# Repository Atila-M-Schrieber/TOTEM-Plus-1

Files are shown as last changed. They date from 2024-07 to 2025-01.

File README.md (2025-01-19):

<picture align="center">
  <source media="(prefers-color-scheme: dark)" srcset="/docs/images/TOTEM_logo_dark.svg">
  <source media="(prefers-color-scheme: light)" srcset="/docs/images/TOTEM_logo_bright.svg">
  TOTEM logo
</picture>

<h1 align="center">T O T E M</h1>
<h2 align="center">Plus 1</h2>

TOTEM Plus 1 is a modified version of the TOTEM keyboard, with an extra pinky key.
It is a 40 key column-staggered choc split keyboard. It is meant to be used with a SEEED XIAO BLE or RP2040.
The build process is pretty much identical, except you need electronics for two more keys.
(Sockets, diodes, switches, and keycaps)
[Here](https://www.hackster.io/geist/totem-a-tiny-splitkeyboard-with-splay-cb2e43) you can read about the process of making it.

The case can fit into a magnetic travel case, like the one
made by [Compression Keyboards](https://compressionkeyboards.com/products/4c-3d-printed-case-kit).
The current V2 case is still missing accenting and some optimization, but is otherwise ready for use,
and works great with the V0 travel case.

While the layout is pretty much identical to the [KLOR KONRAD](https://github.com/GEIGEIGEIST/KLOR),
I prefer the æsthetics of the TOTEM, and I have no need for a rotary encoder on this keyboard.
Also, I wanted to dip my toes into PCB editing, and this seemed like a slightly bigger challenge
(it was) than removing the rotary encoder from the KLOR.

### Additional features:
- [x] I like the idea of using a switch (like the on/off one) as a way to turn a layer on/off,
      especially for a usecase like gaming. Since I'm going to use this wirelessly, I might add
      another switch (same as the power on/off switch) on top of where where the TRRS
      jack would go. I can probably add the footprint without even removing the TRRS footprints.
      This would mean another row or column from one of the UART pins
        - If I'm using the UART pins for something else, like trackpoint support, this won't work
          (or only on one side of the keyboard, ie 'gaming mode' switch on left side, trackpoint on right)
        - In implementing this **I swapped the poles of the TRRS jack** (GND -> TX -> VCC -> GND), so take note
          if you do end up using the wired version and need to debug the TTRS cable (for some reason).
        - There is a lot of overlap with the TRRS through holes - while it might be harder to solder
          due to the conduction, there is plenty of space to solder the switch leads.
    - Alternatively I can add an I/O expander (MCP23017), which is already supported in ZMK
- [x] Splitting the current top half of the case into top and middle sections, where the middle section
      would be the key grid + the 'skirt' of the thumb cluster. This would eliminate the need for supports,
      and would make the exposed key grid take on the texture of the print bed.
      It also allows the removal of the top & bottom parts without having to remove all the keycaps.
- [ ] The current tenting and anti-slip solutions work, but could be improved,
      for example by integrating magnetic stands, for example using a MagSafe phone stand as the mounting and tenting solution.
- [ ] Trackpoint support: ([see this pull request / fork](https://github.com/zmkfirmware/zmk/pull/1751))
      This would be a replacement for the TRRS jacks, since it uses UART.
      I have ordered [this module](https://www.aliexpress.com/item/1005004696754100.html),
      so I'll see if/how I can use it.
***

(The Plus in the 'totem pole' logo is (supposed to be) a hammerhead)

## LAYOUT

TOTEM layout

***

## PCB

[Here](/PCB/) you can find the KiCad files and Gerbers for the TOTEM.

***

## CASE

You can use the TOTEM without a case, but [here](/case/) you can find one I made for it.

***

## BUILD GUIDE

The build guide for the TOTEM can be found [here](/docs/buildguide.md).

***

## FIRMWARE

[My ZMK config](https://github.com/Atila-M-Schrieber/zmk-config) for the TOTEM Plus 1 (wireless with a dongle, using the XIAO BLE)

[Original dongle ZMK config](https://github.com/eigatech/zmk-config/tree/totem-dongle) for the TOTEM wireless + dongle build

***

## PHOTOS

This is the TOTEM Plus 1 in the V2 case optimized for FDM printing.
The case was printed using Gembird gray PETG on an Ender 3 V3 Plus with a 0.6mm nozzle and 0.3mm layer height.
The keycaps used can be found [here](https://github.com/sporkus/PseudoMakeMeKeyCapProfiles) (the Chicago Stenographer version),
and were printed on a Prusa SL1.

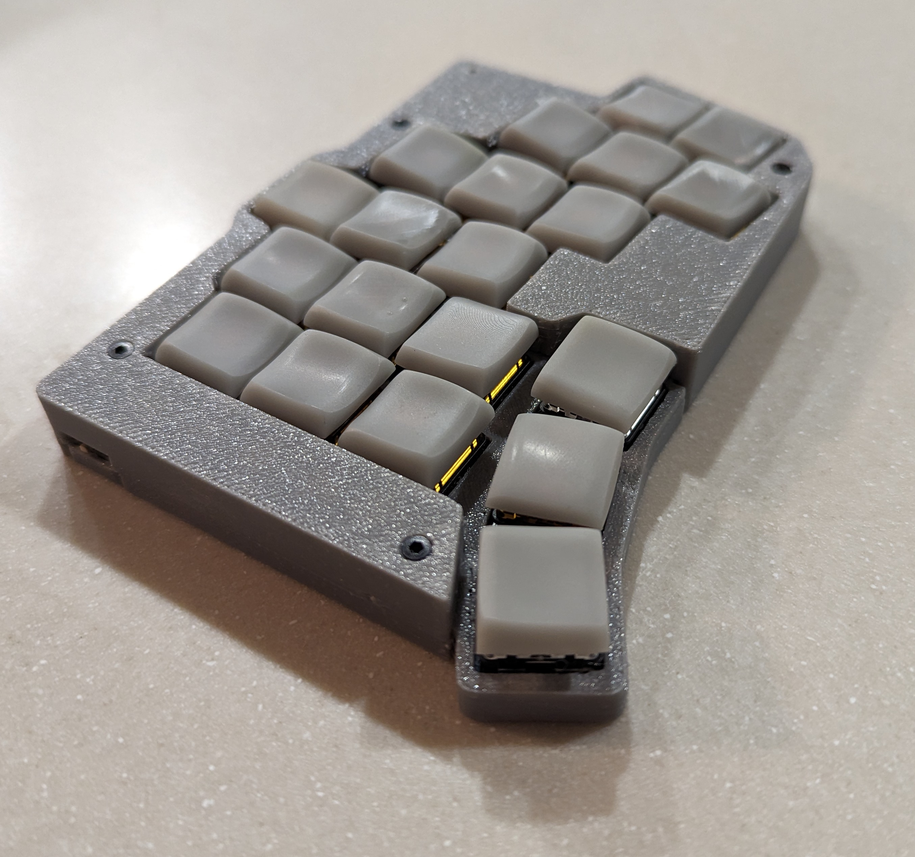
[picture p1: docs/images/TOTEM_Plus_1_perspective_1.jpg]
TOTEM Plus 1 perspective

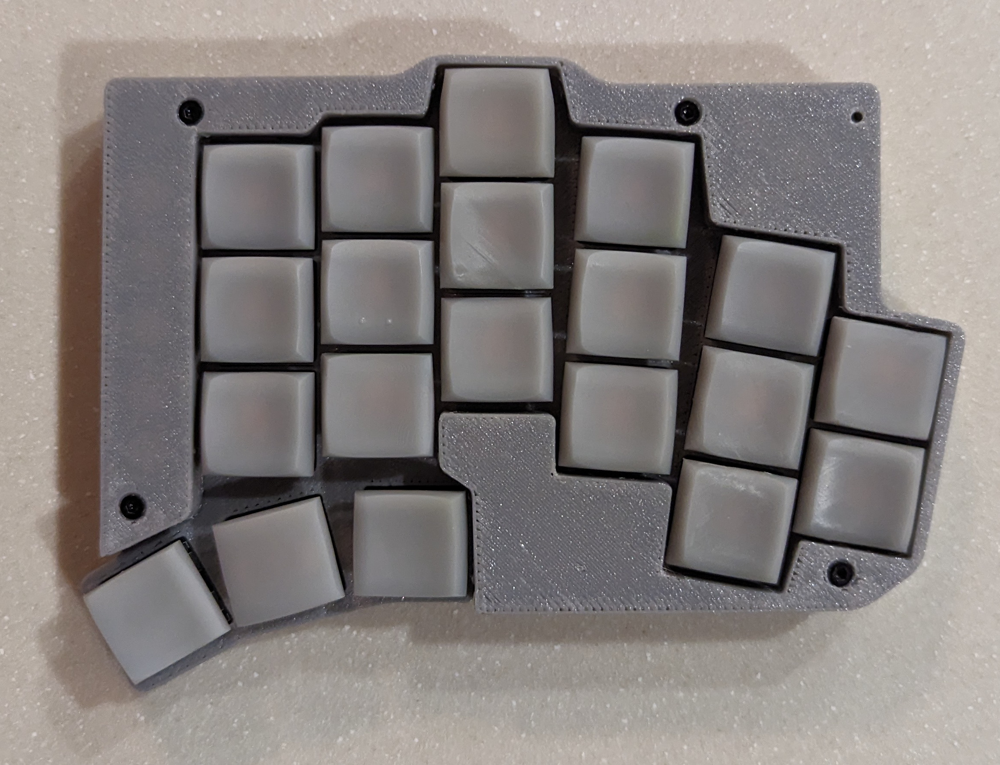
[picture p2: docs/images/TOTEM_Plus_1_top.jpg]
TOTEM Plus 1 top

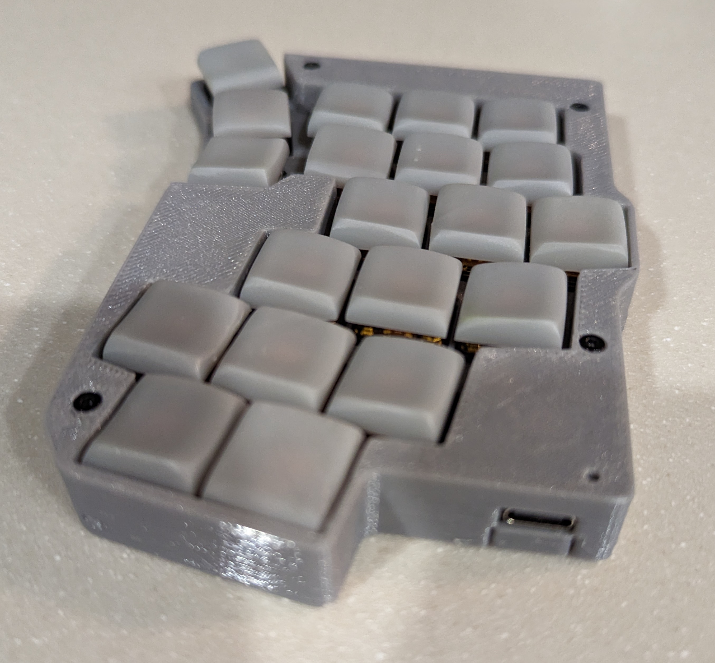
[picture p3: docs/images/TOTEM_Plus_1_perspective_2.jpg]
TOTEM Plus 1 perspective

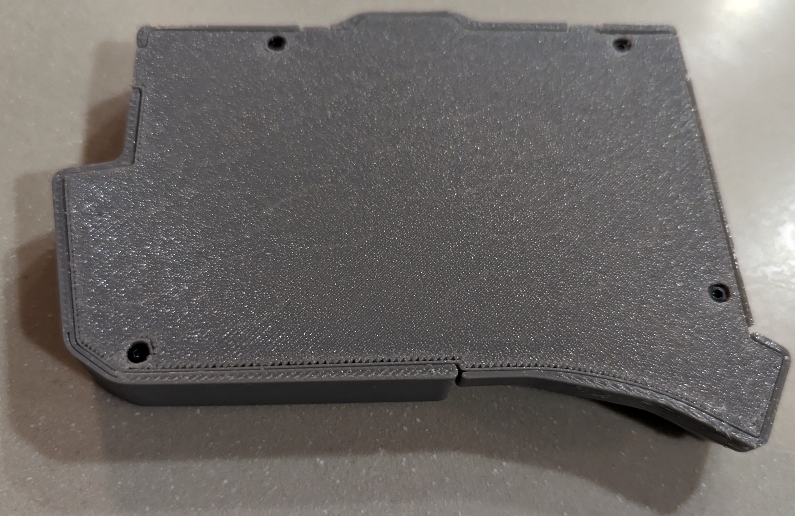
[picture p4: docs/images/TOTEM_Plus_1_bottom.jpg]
TOTEM Plus 1 bottom


The magnet arrangement for the travel case:

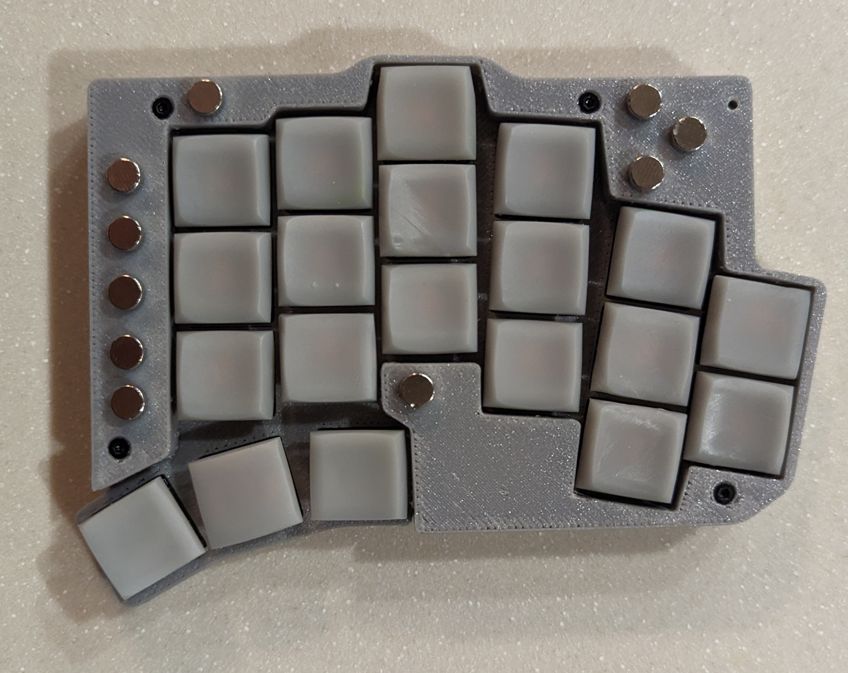
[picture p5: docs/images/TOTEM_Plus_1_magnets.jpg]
TOTEM Plus 1 magnet layout


The travel case:

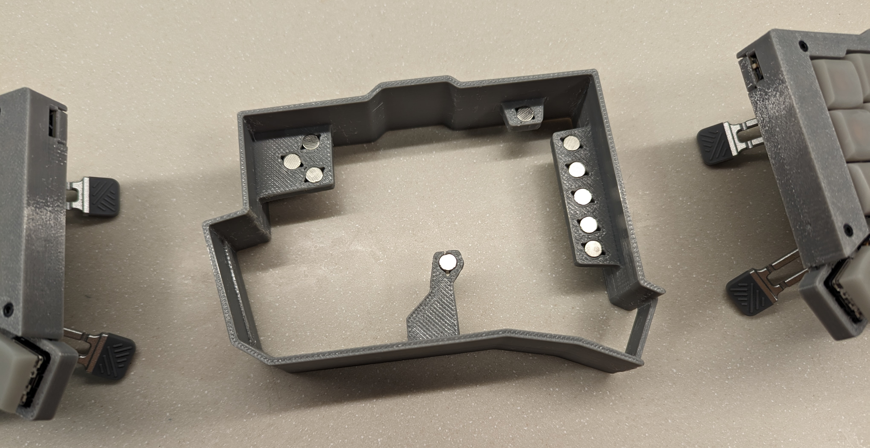
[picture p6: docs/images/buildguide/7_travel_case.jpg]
TOTEM Plus 1 travel case

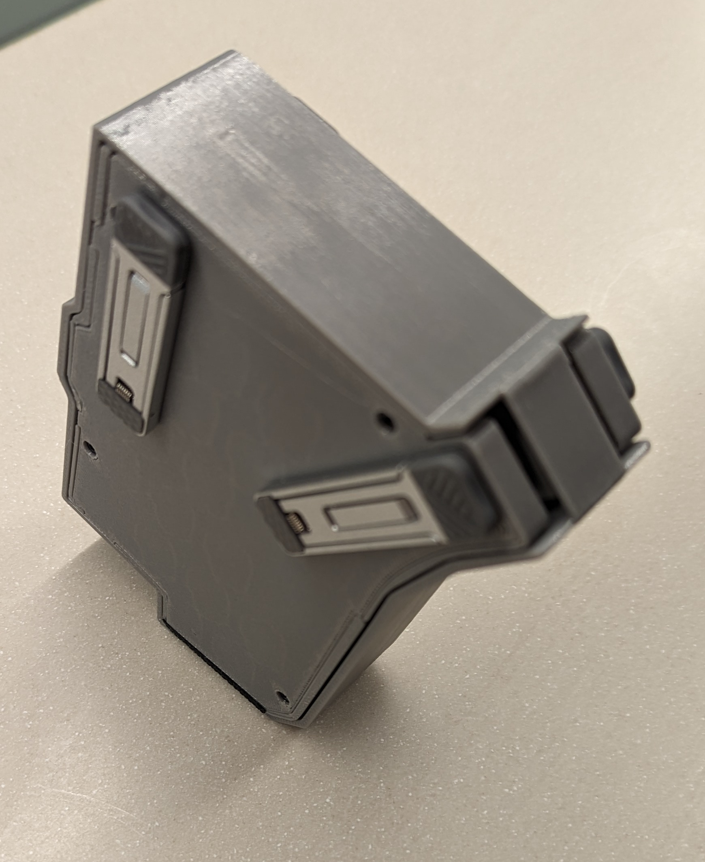
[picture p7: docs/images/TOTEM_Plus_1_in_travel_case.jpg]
TOTEM Plus 1 in travel case


The current V0 travel case is not yet properly optimized for FDM printing,
and is missing some features, like having storage for the dongle.

***

## CREDITS

These credits are by GEIST.

### INSPIRATION

I've added the additional pinky key to make the TOTEM compatible with the layout boards like the [Balbuzard](https://github.com/brow/balbuzard) by [Tom Brow](https://github.com/brow) and the [Osprette](https://github.com/smores56/osprette) by [Sam Mohr](https://github.com/smores56) use, where you put the keybinding of the top left and right keys on an outer pinky key.

### HELP FIXING THINGS

People who helped me create this board and fix stuff

#### PCB
- [Marco "Bob"](https://github.com/GroooveBob)

#### CASE
- [Freya](https://github.com/freya-irl)
- [Bubbleology](https://github.com/bubbleology)

#### FIRMWARE
- [Cem Aksoylar](https://github.com/caksoylar)
- [Grinnie](https://github.com/regicidalplutophage)
- [Alaa Saad Mansour](https://github.com/AlaaSaadAbdo)
- [pekudzu](https://github.com/pekudzu)

If you build a TOTEM I would be pretty happy to see some pictures. And if you want to leave me a tip you can do this [here](https://ko-fi.com/geigeigeist) (but please don't feel pressured)

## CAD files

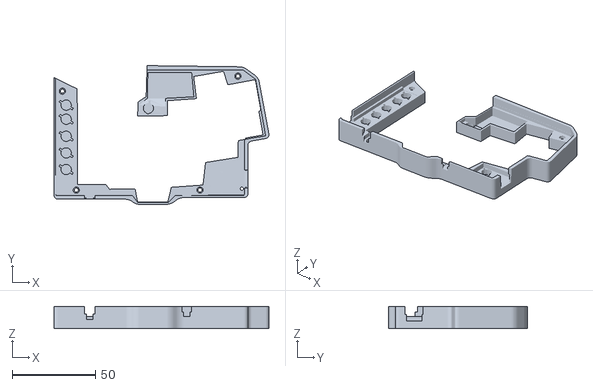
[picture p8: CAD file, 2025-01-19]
case/Plus 1/TOTEM_Plus_1_top_R.stl
128.9 x 83.2 x 13.4

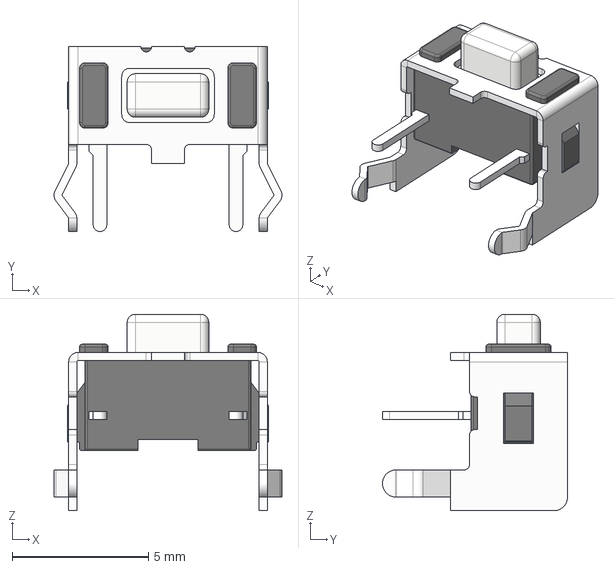
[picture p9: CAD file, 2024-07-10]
PCB/totem_plus_1_0-3/TOTEM3D/SW_SKHLLC.step
8.38 x 6.80 x 7.22 mm

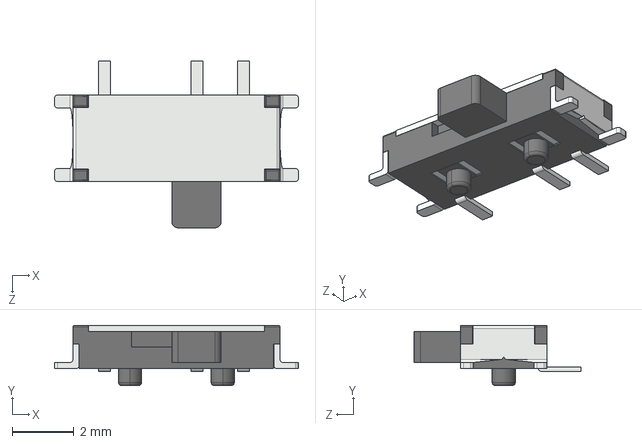
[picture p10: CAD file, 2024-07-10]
PCB/totem_plus_1_0-3/TOTEM3D/MSK12C02.STEP
7.90 x 1.95 x 5.39 mm

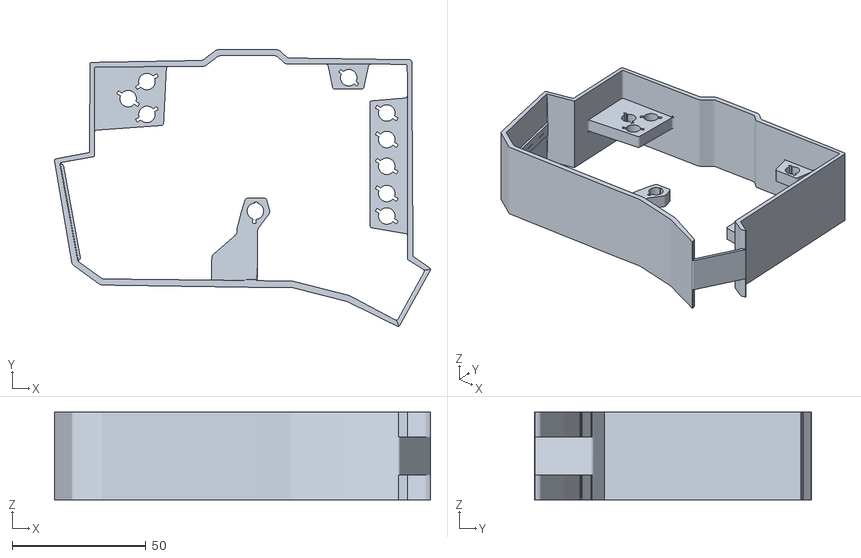
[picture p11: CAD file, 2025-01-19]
case/Plus 1/TOTEM_Plus_1_Travel_Case_V0.stl
140.8 x 103.6 x 32.8

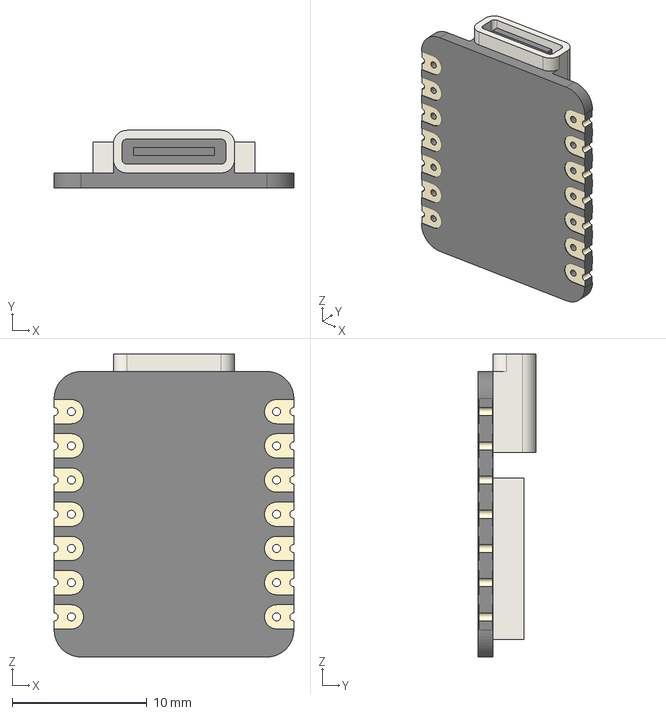
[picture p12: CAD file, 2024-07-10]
PCB/totem_plus_1_0-3/TOTEM3D/xiao-ble-tht.step
17.8 x 4.27 x 22.5 mm

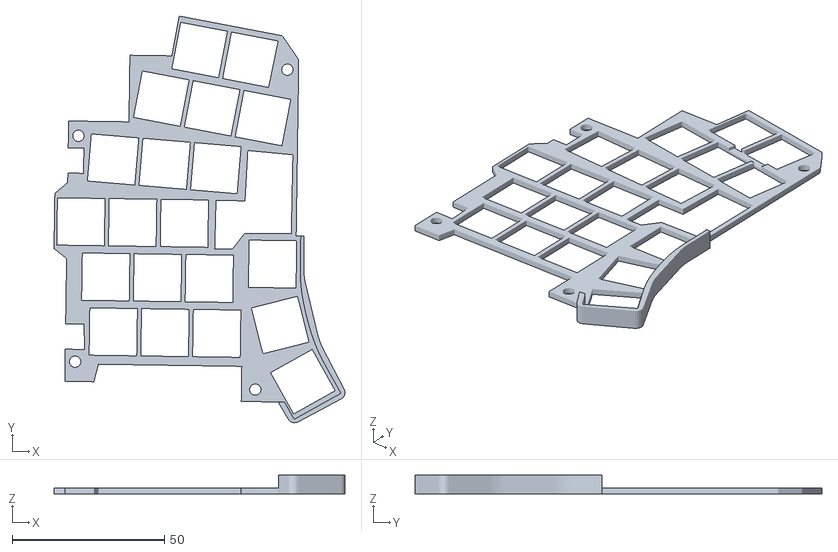
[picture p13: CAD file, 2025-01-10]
case/Plus 1/TOTEM_Plus_1_middle_L.stl
95.6 x 133.5 x 6.23

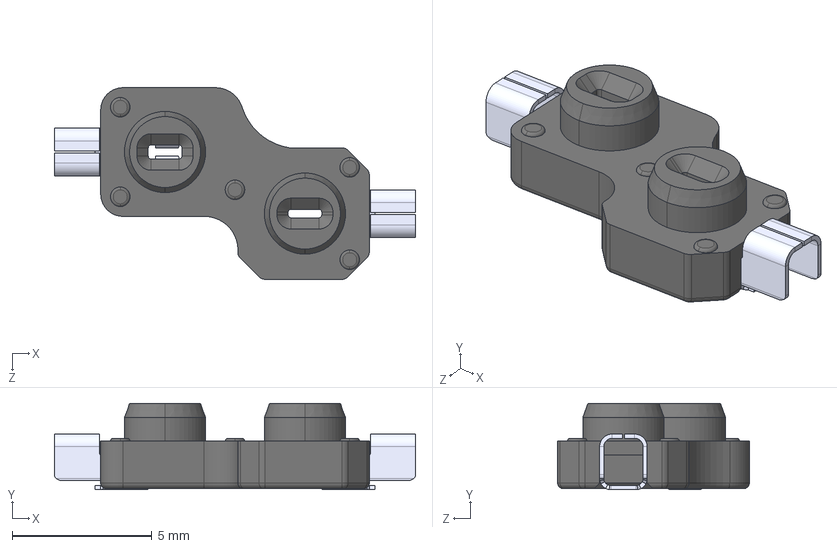
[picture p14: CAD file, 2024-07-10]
PCB/totem_plus_1_0-3/TOTEM3D/Kailh_socket_PG1350_optional.STEP
12.9 x 3.09 x 6.85 mm
pin x 2
socket

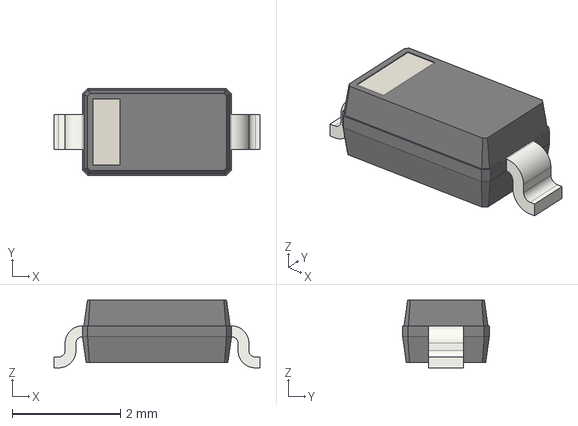
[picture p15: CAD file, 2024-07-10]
PCB/totem_plus_1_0-3/TOTEM3D/D_SOD-123.step
3.80 x 1.60 x 1.25 mm

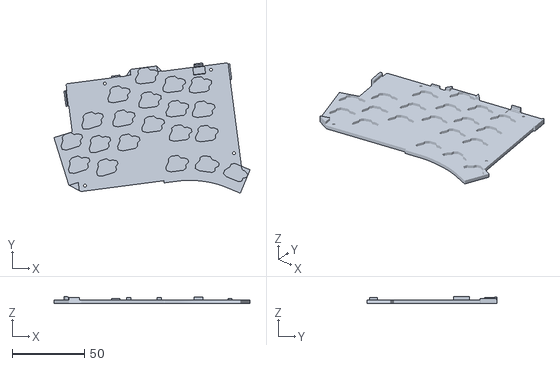
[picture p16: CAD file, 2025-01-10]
case/Plus 1/TOTEM_Plus_1_bottom_L.stl
135.8 x 90.2 x 4.83

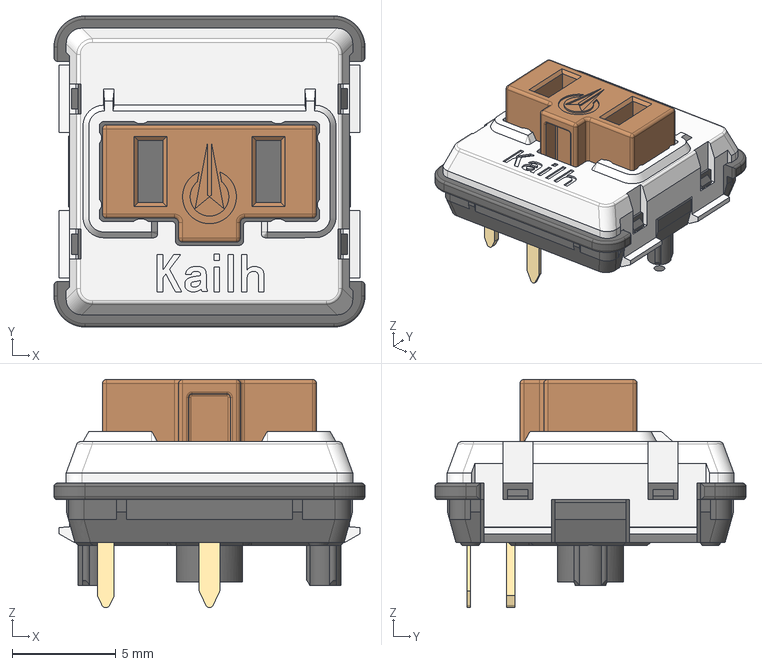
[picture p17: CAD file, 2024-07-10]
PCB/totem_plus_1_0-3/TOTEM3D/Kailh_switch_PG1350_optional.step
15.0 x 15.0 x 11.0 mm

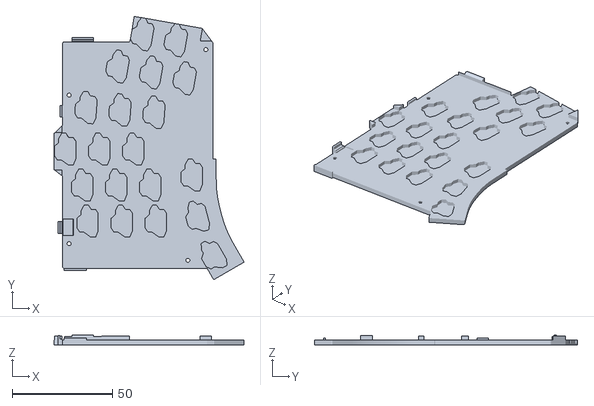
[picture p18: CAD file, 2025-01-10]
case/Plus 1/TOTEM_Plus_1_bottom_R.stl
94.8 x 131.4 x 4.83

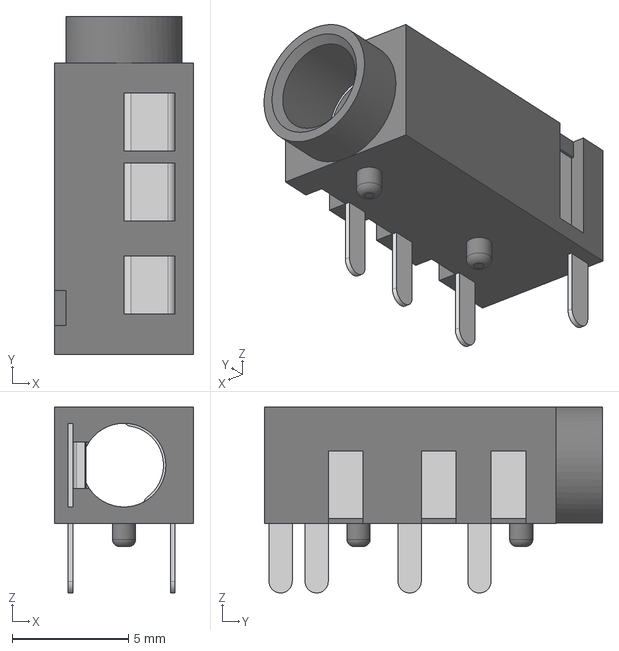
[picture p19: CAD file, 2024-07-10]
PCB/totem_plus_1_0-3/TOTEM3D/PJ320A.STEP
6.00 x 14.6 x 8.00 mm

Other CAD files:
case/Plus 1/TOTEM_Plus_1_top_L.stl
case/Plus 1/TOTEM_Plus_1_middle_R.stl

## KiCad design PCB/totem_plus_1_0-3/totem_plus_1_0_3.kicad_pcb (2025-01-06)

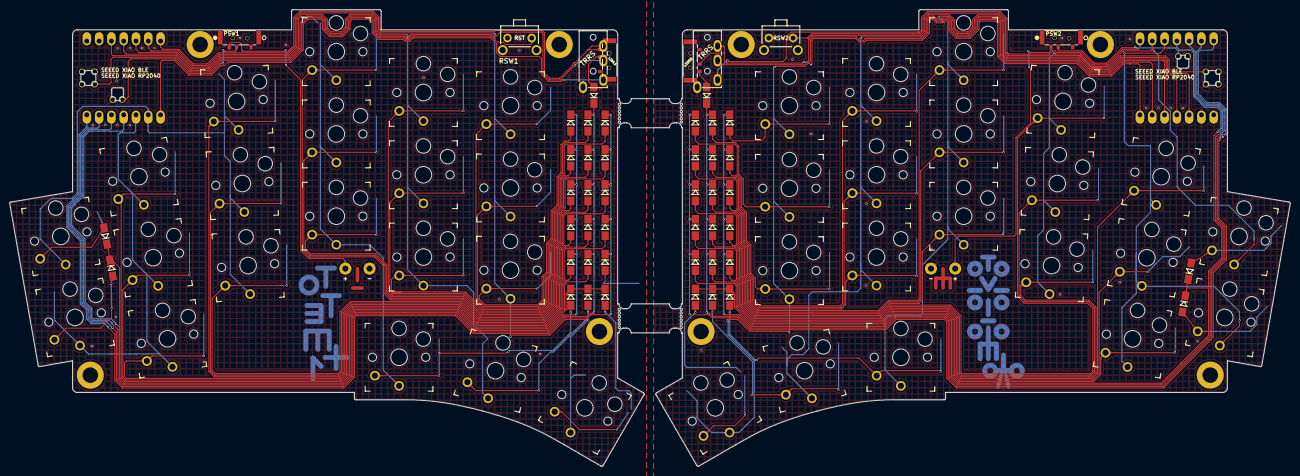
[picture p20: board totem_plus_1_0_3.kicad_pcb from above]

Board: 2 copper layers, 264.6 x 94.4 mm, 96 parts (0 on the bottom side), 74 nets.

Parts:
BAT+1, BAT+2: +; BatteryPad
BATGND1, BATGND2: -; BatteryPad
DL1, DL2, DL3, DL4, DL5, DL6, DL7, DL8, DL9, DL10, DL11, DL12, DL13, DL14, DL15, DL16, DL17, DL18, DL19, DL20: D_Small; Diode_SOD123
DLL1: D_Small; Diode_SOD123
DR1, DR2, DR3, DR4, DR5, DR6, DR7, DR8, DR9, DR10, DR11, DR12, DR13, DR14, DR15, DR16, DR17, DR18, DR19, DR20: D_Small; Diode_SOD123
DRL1: D_Small; Diode_SOD123
J1, J2: MJ-4PP-9; MJ-4PP-9_1side
LSWL1: SW_SPDT; MSK12C02
LSWR1: SW_SPDT; MSK12C02
PSW1, PSW2: SW_SPDT; MSK12C02
RSW1, RSW2: SW_Push; SKHLLCA010
SWL1, SWL2, SWL3, SWL4, SWL5, SWL6, SWL7, SWL8, SWL9, SWL10, SWL11, SWL12, SWL13, SWL14, SWL15, SWL16, SWL17, SWL18, SWL19, SWL20: SW_Push_45deg; Kailh_socket_PG1350_optional
SWR1, SWR2, SWR3, SWR4, SWR5, SWR6, SWR7, SWR8, SWR9, SWR10, SWR11, SWR12, SWR13, SWR14, SWR15, SWR16, SWR17, SWR18, SWR19, SWR20: SW_Push_45deg; Kailh_socket_PG1350_optional
U1, U2: xiao-ble; xiao-ble-smd-cutout

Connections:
BAT+_L: PSW1.2 (B), U1.19 (BAT)
BAT+_R: PSW2.2 (B), U2.19 (BAT)
COL0_L: SWL1.1, SWL6.1, SWL11.1, SWL16.1, U1.5 (A8_SDA/0.04_H)
COL0_R: SWR1.1, SWR6.1, SWR11.1, SWR16.1, U2.5 (A8_SDA/0.04_H)
COL1_L: SWL2.1, SWL7.1, SWL12.1, SWL17.1, U1.6 (A9_SCL/0.05_H)
COL1_R: SWR2.1, SWR7.1, SWR12.1, SWR17.1, U2.6 (A9_SCL/0.05_H)
COL2_L: SWL3.1, SWL8.1, SWL13.1, SWL18.1, U1.11 (A6_MOSI/1.15)
COL2_R: SWR3.1, SWR8.1, SWR13.1, SWR18.1, U2.11 (A6_MOSI/1.15)
COL3_L: SWL4.1, SWL9.1, SWL14.1, SWL19.1, U1.10 (A5_MISO/1.14)
COL3_R: SWR4.1, SWR9.1, SWR14.1, SWR19.1, U2.10 (A5_MISO/1.14)
COL4_L: SWL5.1, SWL10.1, SWL15.1, SWL20.1, U1.9 (A7_SCK/1.13)
COL4_R: SWR5.1, SWR10.1, SWR15.1, SWR20.1, U2.9 (A7_SCK/1.13)
COL5_L: J1.B, LSWL1.3 (C), U1.8 (B9_RX/1.12)
COL5_R: J2.B, LSWR1.2 (B), U2.8 (B9_RX/1.12)
GND_L: BATGND1.1, J1.A, RSW1.2, U1.13 (GND), U1.18 (GND), U1.20 (GND)
GND_R: BATGND2.1, J2.A, RSW2.2, U2.13 (GND), U2.18 (GND), U2.20 (GND)
unnamed: DL1.2 (A), SWL1.2
unnamed: DL2.2 (A), SWL2.2
unnamed: DL3.2 (A), SWL3.2
unnamed: DL4.2 (A), SWL4.2
unnamed: DL5.2 (A), SWL5.2
unnamed: DL6.2 (A), SWL6.2
unnamed: DL7.2 (A), SWL7.2
unnamed: DL8.2 (A), SWL8.2
unnamed: DL9.2 (A), SWL9.2
unnamed: DL10.2 (A), SWL10.2
unnamed: DL11.2 (A), SWL11.2
unnamed: DL12.2 (A), SWL12.2
unnamed: DL13.2 (A), SWL13.2
unnamed: DL14.2 (A), SWL14.2
unnamed: DL15.2 (A), SWL15.2
unnamed: DL16.2 (A), SWL16.2
unnamed: DL17.2 (A), SWL17.2
unnamed: DL18.2 (A), SWL18.2
unnamed: DL19.2 (A), SWL19.2
unnamed: DL20.2 (A), SWL20.2
unnamed: DLL1.2 (A), LSWL1.2 (B)
unnamed: DR1.2 (A), SWR1.2
unnamed: DR2.2 (A), SWR2.2
unnamed: DR3.2 (A), SWR3.2
unnamed: DR4.2 (A), SWR4.2
unnamed: DR5.2 (A), SWR5.2
unnamed: DR6.2 (A), SWR6.2
unnamed: DR7.2 (A), SWR7.2
unnamed: DR8.2 (A), SWR8.2
unnamed: DR9.2 (A), SWR9.2
unnamed: DR10.2 (A), SWR10.2
unnamed: DR11.2 (A), SWR11.2
unnamed: DR12.2 (A), SWR12.2
unnamed: DR13.2 (A), SWR13.2
unnamed: DR14.2 (A), SWR14.2
unnamed: DR15.2 (A), SWR15.2
unnamed: DR16.2 (A), SWR16.2
unnamed: DR20.2 (A), SWR17.2
unnamed: DR17.2 (A), SWR18.2
unnamed: DR18.2 (A), SWR19.2
unnamed: DR19.2 (A), SWR20.2
unnamed: DRL1.2 (A), LSWR1.3 (C)
RESET_L: RSW1.1, U1.17 (RESET)
RESET_R: RSW2.1, U2.17 (RESET)
ROW0_L: DL1.1 (K), DL2.1 (K), DL3.1 (K), DL4.1 (K), DL5.1 (K), U1.1 (A2/0.02_H)
ROW0_R: DR1.1 (K), DR2.1 (K), DR3.1 (K), DR4.1 (K), DR5.1 (K), U2.1 (A2/0.02_H)
ROW1_L: DL6.1 (K), DL7.1 (K), DL8.1 (K), DL9.1 (K), DL10.1 (K), DLL1.1 (K), U1.2 (A4/0.03_H)
ROW1_R: DR6.1 (K), DR7.1 (K), DR8.1 (K), DR9.1 (K), DR10.1 (K), DRL1.1 (K), U2.2 (A4/0.03_H)
ROW2_L: DL11.1 (K), DL12.1 (K), DL13.1 (K), DL14.1 (K), DL15.1 (K), U1.3 (A10/0.28)
ROW2_R: DR11.1 (K), DR12.1 (K), DR13.1 (K), DR14.1 (K), DR15.1 (K), U2.3 (A10/0.28)
ROW3_L: DL16.1 (K), DL17.1 (K), DL18.1 (K), DL19.1 (K), DL20.1 (K), U1.4 (A11/0.29)
ROW3_R: DR16.1 (K), DR17.1 (K), DR18.1 (K), DR19.1 (K), DR20.1 (K), U2.4 (A11/0.29)
TX_L: J1.D, U1.7 (B8_TX/1.11)
TX_R: J2.D, U2.7 (B8_TX/1.11)
VBAT_L: BAT+1.1, PSW1.3 (C)
VBAT_R: BAT+2.1, PSW2.3 (C)
VCC_L: J1.C, U1.12 (3V3)
VCC_R: J2.C, U2.12 (3V3)

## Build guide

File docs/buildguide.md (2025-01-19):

# TOTEM BUILD GUIDE

## PART LIST

### REQUIRED PARTS

| Part name | Count | Remarks |
| :--- | :---: | :--- |
| TOTEM PCB | 01 | You can find the files for it [here](/PCB/) |
| Seeed XIAO | 02 | You can choose between the BLE version (wireless) or the RP2040 version (wired) |
| Choc key switch | 40 | Kailh Choc low profile key switches |
| diodes 1N4148W  | 40 | These are surface mount diodes in SOD123 package |
| 1u Choc keycaps | 40 | You can use the black or white keycaps from Kailh, but I recommend MBK, LDSA or CFX keycaps |
| reset button | 02 | Alps SKHLLCA010 |
| USB-C cable | 01 | For connecting the keyboard to your PC |
| power switch | 02 | MSK12C02 (only required for the Bluetooth build) |
| Lipo battery | 02 | There is space for a 15 x 22 x 7.5 mm battery (only required for the Bluetooth build) |
| TRRS jack | 02 | MJ-4PP-9 or PJ320A (only required for the wired build)|
| TRRS cable | 01 | Alternatively, you can use a TRS cable for [half-duplex](https://github.com/qmk/qmk_firmware/blob/master/docs/serial_driver.md#usart-half-duplex) (only required for the wired build)|

### OPTIONAL PARTS

| Part name | Count | Remarks |
| :--- | :---: | :--- |
| switch socket | 40 | Switch sockets for Kailh choc switches |
| toggle switch | 1/2 | Extra toggle switch(es) to act as layer switch(es) MSK12C02 (same as power switch), only compatible with the Bluetooth build |
| diodes 1N4148W | 1/2 | Extra diode(s) for layer switch(es) SOD123, only compatible with the Bluetooth build |

### 3DP CASE PARTS

| Part name | Count | Remarks |
| :--- | :---: | :--- |
| 3D printed case | 02 | Find the case files [here](/case/Plus 1) |
| 6mm M2 standoffs | 08 | 6mm round standoffs for screwing the top and bottom of the case together |
| 6mm M2 countersunk screws | 16 ||
| 6x3mm magnets (optional) | 40 | For magnetically attaching the two halves for travel |
| 3D printed travel case (optional) | 1 | For securing the two halves for travel |
| 8.5mm rubber feet (optional) | 8 | they can also be smaller |
| Anti-Slip adhesive sheet (optional) | 1 | As alternative to rubber feet, example source [here](https://aliexpress.com/item/1005005377684110.html) |
| Tenting feet | 4 | Example source [here](https://aliexpress.com/item/1005005605228469.html) |

### DONGLE PARTS
| Part name | Count | Remarks |
| :--- | :---: | :--- |
| Seeed XIAO | 01 | (3 total) as a dongle |
| Seeed XIAO case | 01 | optional, for aesthetics |

## INTRODUCTION

Here is an overview of where and on which side each component needs to be soldered (click on the image to see a larger version).
This is pretty much the same for the Plus 1, except for the extra key.

TOTEM solder guide

***

## BREAK OFF HALVES

The PCB comes in one piece. You need to break it into two halves.

TOTEM PCB

After breaking them apart, you're left with some sprue marks, which you can remove with a file if you like, but you don't need to.

> **Warning**
> You should wear a mask while doing this since the FR4 dust is considered to be toxic.

PCB sprue marks

I paint the edges black using a sharpie, so they fit better with the top and bottom, but that's optional too. This is unnecessary for use in the case.

PCB edges

***

## DIODES

The diodes need to be soldered on the top of the PCB. Pay attention to their orientation:  They have a small line on one side, which should be on the side the arrow on the PCB is facing to.

<p align="center">
<picture>
  <source media="(prefers-color-scheme: dark)" srcset="/docs/images/buildguide/diodes_dark.svg">
  <source media="(prefers-color-scheme: light)" srcset="/docs/images/buildguide/diodes_bright.svg">
  diode orientation
</picture>
</p>

Apply a small amount of solder on one pad.

Solder on one pad

Then use tweezers to place the diode on the pads and reheat the solder to secure the diode.

Solder diode

Now you can solder the second pad.

***

## SWITCH SOCKETS (optional)

Here you can apply the same technique as used for the diodes: Apply some solder on one of the pads first.

switch sockets pad

Then place the switch socket in the silk screen markings. The orientation matters here too. Especially if you plan on using the case.

<p align="center">
<picture>
  <source media="(prefers-color-scheme: dark)" srcset="/docs/images/buildguide/socket_dark.svg">
  <source media="(prefers-color-scheme: light)" srcset="/docs/images/buildguide/socket_bright.svg">
  hotswap socket orientation
</picture>
</p>

hotswap socket right and wrong orientation

Then reheat the solder.
Apply some pressure with a pair of tweezers to make sure the socket is fully seated.\
Now solder the second pad.

switch socket soldered

***

## POWER SWITCHES (only required for Bluetooth build)

(Also applies to the layer switches included in the Plus 1 design.)

Apply a tiny bit of solder on the bigger, outer pads on top of the PCB.

power switch pads

The power switch has some tiny knobs on its bottom, which fit into the PCB holes. Hold it in place with tweezers and then reheat the solder on the pad. After this, you can solder the other pad and the three pins.

power switch

***

## RESET SWITCHES

Insert the switch into the top of the PCB.

reset switch

I placed the footprint a bit more towards the edge, than it's meant to be, to integrate it better into the case. Therefore the tiny stabilizer on the bottom of the switch doesn't touch the PCB anymore. Make sure it is aligned with the PCB vertically, so it's oriented correctly.

reset switch orientation

Then solder the four pins on the bottom to the PCB

reset switch solder

***

## TRRS JACKS (optional)

> **Warning**
> You don't need the TRRS jacks for running the TOTEM with ZMK. Actually, you can damage your board when connecting it through TRRS, while also connected to a battery.

Install the TRRS jack on the bottom side of the PCB. The place where you should insert it is marked with a white line.

TRRS jack

You may want to use some masking tape to hold it in place since you need to solder it on the bottom.

TRRS jack taped

Then solder the pins on the bottom to the PCB.

TRRS jack soldered

***

## MICROCONTROLLER

> **Warning**
> First flash the microcontroller to make sure it works, before soldering it in. Especially since you can't use sockets.

Place the microcontroller in its place.

> **Note**
> If you're struggling with keeping it in place you can use the headers, which came with it, and some double-sided tape. But make sure it sits flat on the PCB. Otherwise, the case won't fit.

Apply some flux and try to hold the iron at an angle where you touch the pads of the microcontroller and the PCB while adding solder.

soldering MCU

The pads on the back are a bit fiddly to solder, so you should add a lot of flux to the pads on the microcontroller first. Then apply the same technique as on the front: Try to touch the pads on the microcontroller and the PCB before adding solder.

soldering MCU back

***

## BATTERY (optional)

> **Warning**
> You don't need the battery for running the TOTEM with QMK. Actually, you can damage your board when connecting it through TRRS, while also connected to a battery.

You probably need to shorten the cables and tin them, since the length needs to be pretty short, to fit. I've also plasti dipped mine.

shorten battery cables

> **Warning**
> Before attaching the battery in any way to the PCB set the power switch to off (right on both sides).

You can see which cable needs to go in which eye by the silkscreen below the eyes. Red is + / Black is -.

battery face

Attach the wires of the battery to the pads and solder them in.

Ouch

***

## CLEANING

You can use an old toothbrush and some isopropanol to clean it from residues.

***

## FIRMWARE

If you have not already flashed the firmware to the microcontroller you should do it now.\
[Here](https://github.com/Atila-M-Schrieber/zmk-config) you can find the ZMK firmware for the TOTEM Plus 1.\

Probably a good idea to also install switches to make sure all of them work, before inserting the board into the case.

PCB with switches

***

## CASE

The case is made up of three parts: top, middle, and bottom.
The top holds the magnets, and hides most of the electronics,
the middle surrounds the switches and protects the thumb cluster,
and the bottom protects the switch sockets.
The 6mm spacers go through the top and middle sections,
and the case is held together by screws inserted into the spacers from the bottom and top sections.

1. Press the PCBs into the bottom section of the case. Don't be afraid to apply some force until the bottom is firmly in place.
2. Screw in the bottom 4 screws - they will self-tap here.
3. From the top, screw the spacers onto the screws, until their bottoms are flush with the PCB.
   It should look like this:
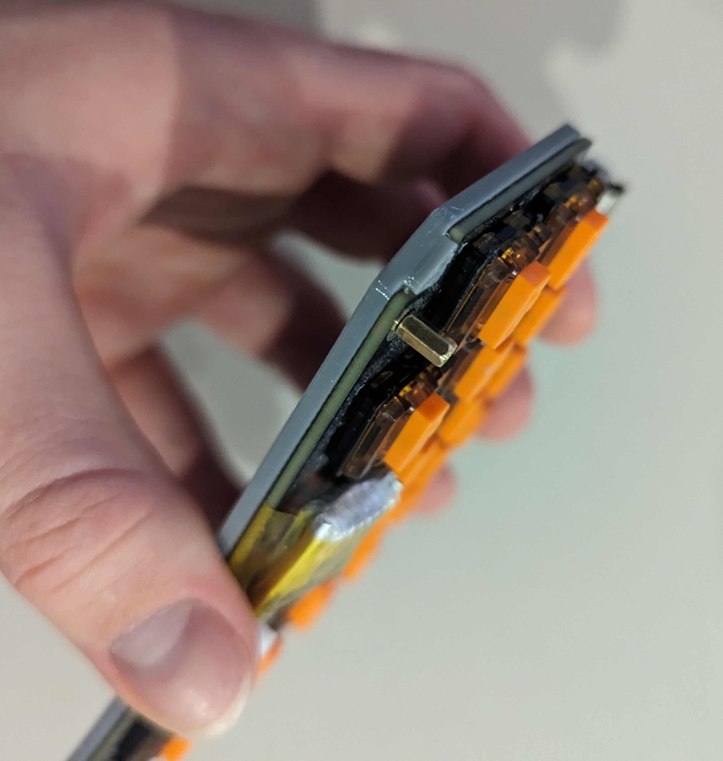
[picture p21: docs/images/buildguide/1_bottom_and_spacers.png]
Bottom attached, with spacers
   
4. Next, align the middle section with the four spacers, and push it down evenly until it is flush with the PCB.
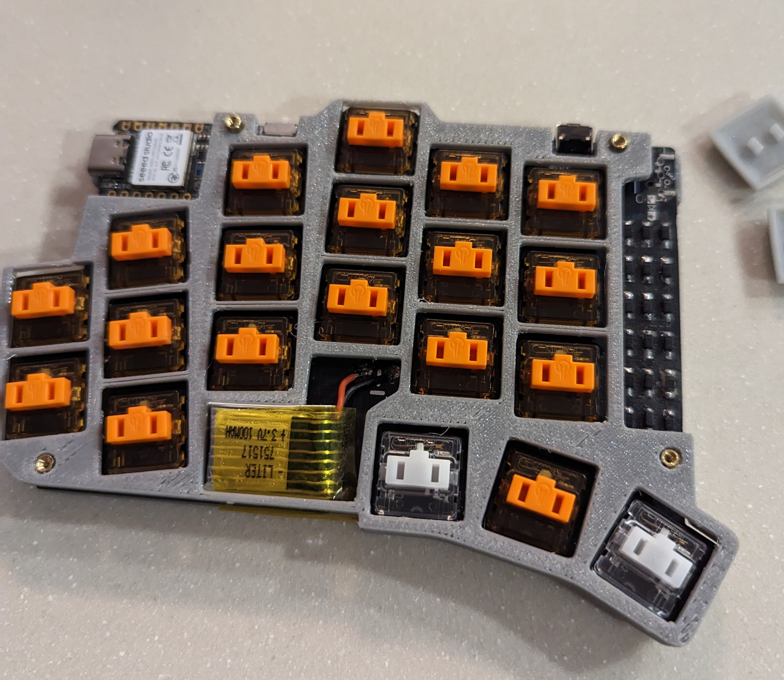
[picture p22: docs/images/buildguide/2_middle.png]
Middle aligned
   
   You might want to use a small blunt object to make sure it is flush at all points.
   Make sure the 'skirt' around the thumb cluster is fully down by squeezing the middle and bottom sections together there.
5. (Optional, if you want to use the travel case.) Insert one 6x3mm magnet into each hole in the top sections.
   They should all face the same direction,
   and the two top sections should snap together with no opposite polarities.
   If some magnets are hard to insert, you can use a small blunt object to press them in.
   If some magnets are too loose, use superglue.
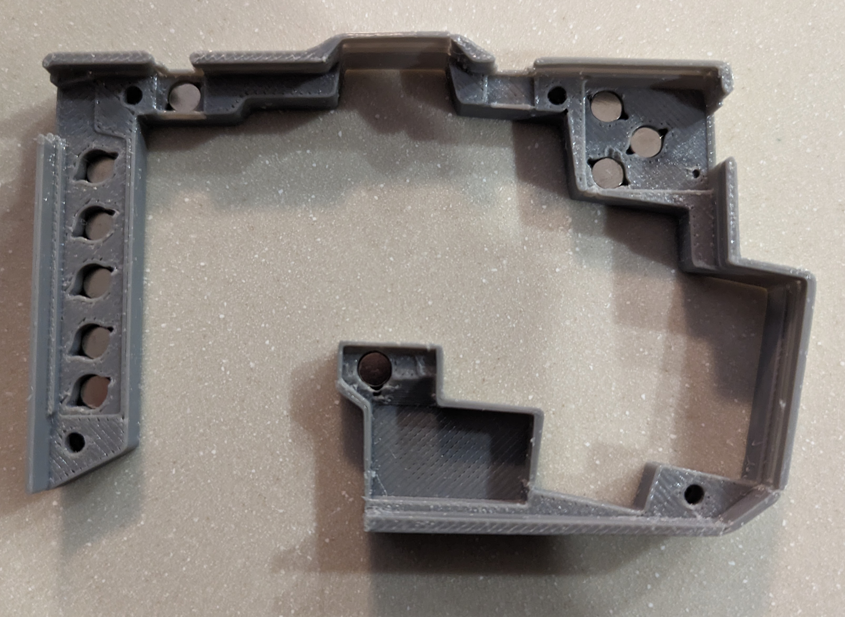
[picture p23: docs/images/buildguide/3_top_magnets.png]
Top with magnets
   
6. Align the top section with the spacers, and push it down until its perimeter is flush with the bottom.
   I recommend flipping the board upside down, and pushing from the bottom section's edges,
   as some less supported bits can get bent out if done carelessly.
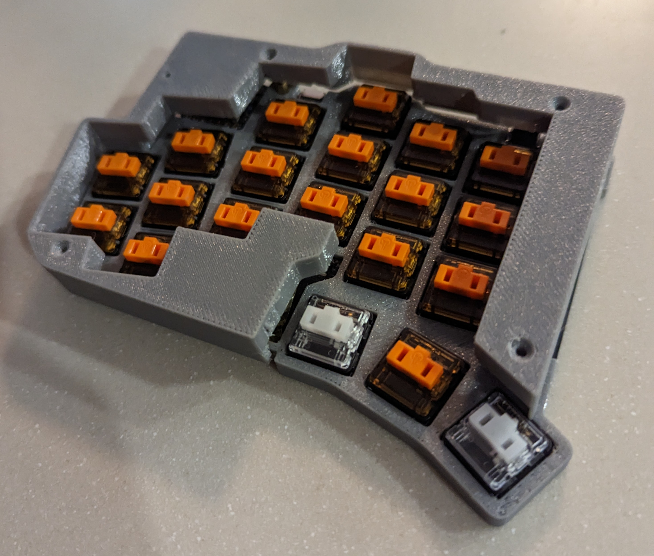
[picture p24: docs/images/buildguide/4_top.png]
Top aligned on spacers
   
7. Insert the top screws until flush with the case, and alternating top and bottom tighten the screws.
8. Apply the tenting feet to the bottom of the cases.
   I recommend spacing them so when tented, the edge of the case at the pinky keys lays flat.
   In the image, I applied the feet so I don't cover any screws, but this is slightly less stable than it could have been.
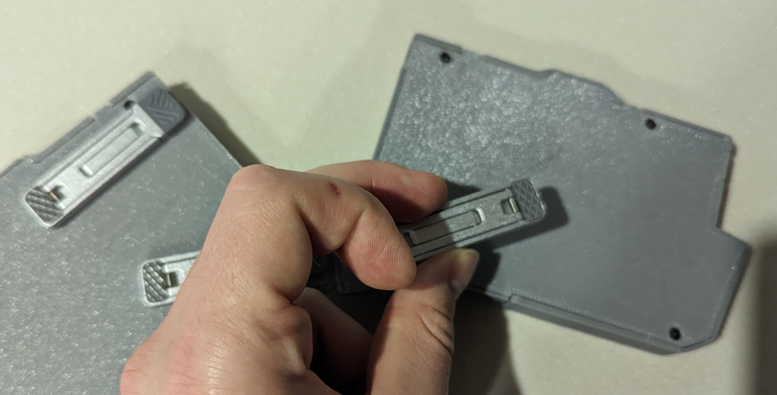
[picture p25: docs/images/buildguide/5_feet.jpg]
Applying the feet
   
9. Apply a thin strip of the adhesive rubber mat to prevent slipping.
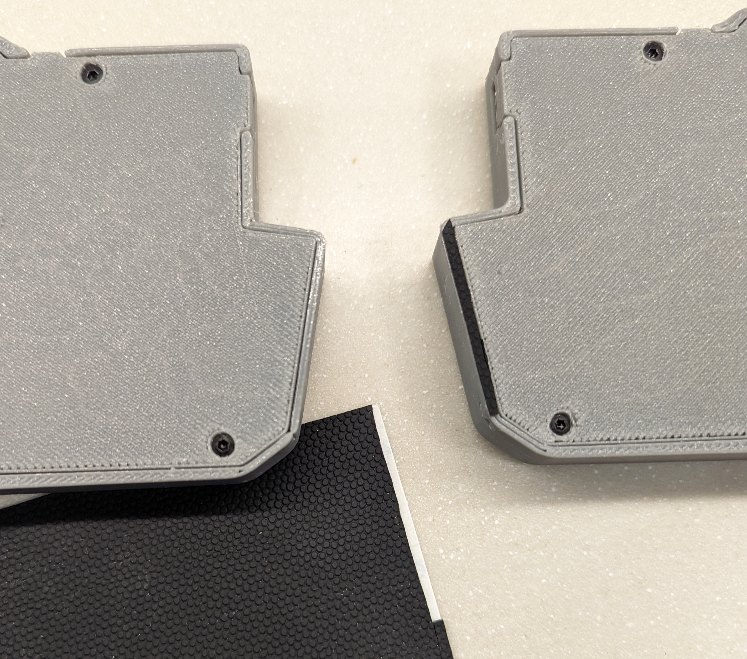
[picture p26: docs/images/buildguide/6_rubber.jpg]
Applying the rubber mat
   

That completes the case!

For the travel case, insert two 6x3mm magnets in each hole. (Or one 6x6mm magnet.)
I recommend tuning your printer by cutting out one hole and printing it at very slightly different scales.
Once you find the perfect press-fit scale, you can use Blender to modify the holes:
Open the travel case stl in Blender, go into edit mode, press 1 to select vertices,
go into wireframe mode, click the z-axis on the compass to get a top-down view,
select all vertices associated with the holes with any selection tool,
and scale them using "Individual Origins" **excluding the Z-axis** using shift-z to the setting you found.

I used a woodworking clamp to press the magnets into place, but any sort of vice should work.

Alternatively, you can glue them in with superglue.

Travel case

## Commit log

2024-07-09 Initial update from original
    [totem_0_3.kicad_sch]
2024-07-10 Updated schematic to match design. Placed both new switches in the correct position. Re-routed traces on left side. Next: rerouting on the right side.
2024-07-10 Renamed the PCB directory to match the new keyboard name
    [D_SOD-123.step, Kailh_socket_PG1350_optional.STEP, Kailh_switch_PG1350_optional.step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]
2024-07-10 Fixed key designations on right side, and cleared right-edge tracks.
    [totem_0_3.kicad_sch, totem_plus_1_0_3.kicad_sch]
2024-07-12 Re-did a bit on the right end, mostly for aesthetics. Fixed discontinuity in PCB edge cut. Routing should (hopefully) be final.
2024-07-13 Small PCB adjustments, README update
2024-07-13 Added option to add a switch (like the power switch) instead of a TRRS jack as a 'key' - ie as a layer switch
    [totem_plus_1_0_3.kicad_sch]
2024-07-13 Added silkscreen art, and small readme changes
2024-07-13 Additional silkscreen art
2024-07-13 Silkscreen changes so things are more visible around the now-cluttered TRRS jacks
2024-07-14 Added teardrops to vias, exported gerbers (the .zip should now work)
2024-07-15 Fixed gerber zip
2024-08-15 updates PCB to remove the self-grounding error, and updates the README accordingly
    [totem_plus_1_0_3.kicad_sch]
2025-01-06 Added case, updated README
    [TOTEM_Plus_1_bottom_halves.stl, TOTEM_Plus_1_top_halves.stl, totem_plus_1_0_3.kicad_pcb]
2025-01-10 Updated case design to V2, updated README
    [TOTEM_Plus_1_bottom_L.stl, TOTEM_Plus_1_bottom_R.stl, TOTEM_Plus_1_bottom_halves.stl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]
2025-01-10 Fix to STL
    [TOTEM_Plus_1_middle_L.stl]
2025-01-19 Adds travel case, and updates build guide.
    [TOTEM_Plus_1_Travel_Case_V0.stl, TOTEM_Plus_1_top_L.stl, TOTEM_Plus_1_top_R.stl]
